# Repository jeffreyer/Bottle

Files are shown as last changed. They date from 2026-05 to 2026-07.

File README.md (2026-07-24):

# Bottle - 可编程 LED 矩阵设备

Bottle 是一个基于 ESP32-S3 的可编程 LED 矩阵设备，支持通过 Lua 脚本创建动态动画效果。它集成了重力感应、音频采集、蓝牙配置等功能，适合创建互动式视觉艺术作品。

## 主要特性

### 硬件能力
- **LED 矩阵**: 17×8 / 32x8 全彩 LED 阵列，支持动态动画
- **重力感应**: LIS3DH 三轴加速度计，支持姿态检测和重力交互
- **音频采集**: 支持 I2S/PDM 麦克风，实时 FFT 频谱分析（17 / 32 频段）
- **音频录制**: 支持录制原始 PCM 音频到 U盘
- **触摸控制**: 电容触摸按键，支持短按、长按、超长按
- **蓝牙功能**: 
  - BLE 配置服务（通过手机 App 配置设备）
  - BLE HID 鼠标模式（将设备用作蓝牙鼠标）
- **USB 功能**: 
  - **USB 复合设备**: 同时支持串口（CDC）和 U盘（MSC）
  - **串口调试**: 始终可用
- **电源管理**: 电池电量监测、自动休眠、低功耗模式

### 软件特性
- **Lua 脚本引擎**: 基于 Lua 5.4.7，支持热加载动画模块
- **模块化架构**: 内置多种动画效果（文字滚动、频谱显示、重力粒子、沙漏、蜡烛等）
- **云端配置**: 支持通过蓝牙从云端下载和配置模块
- **安全机制**: 栈溢出保护、数组边界检查、指令限制
- **持久化存储**: NVS 配置存储、Flash 文件系统

## 硬件设计

本项目包含完整的硬件设计文件（Altium Designer 格式）：

- **PCB 设计**: [Hardware](Hardware/) 目录
  - 硬件组装说明: [README.md](Hardware/README.md)
  - 主板原理图: [main.schdoc](Hardware/main.schdoc)
  - LED 阵列原理图: [led_array.schdoc](Hardware/led_array.schdoc)
  - PCB 布局: [bottle.PcbDoc](Hardware/bottle.PcbDoc)
  - Gerber 文件: [Gerber.rar](Hardware/Gerber.rar)

**核心器件**:
- MCU: ESP32-S3 (N4R2 配置 - 4MB Flash, 2MB PSRAM)
- 加速度计: LIS3DH
- LED: WS2812B 阵列
- 麦克风: I2S/PDM 数字麦克风（板子支持MSM261D3526Z1CM，MSM261S3526Z0CM，可通过串口命令 mic=1/0 切换）

## 快速开始

### 环境准备

1. **安装开发工具**
   - [Visual Studio Code](https://code.visualstudio.com/)
   - [PlatformIO IDE](https://platformio.org/install/ide?install=vscode) 扩展

2. **克隆仓库**
   ```bash
   git clone <repo-url>
   cd Bottle
   ```

### 编译和上传
- 当前有长短版两个版本，编译前需要修改common.h文件，修改第21行，BOTTLE_V4为长版32\*8像素，注释掉为短版17\*8像素，根据需要选择是否注释
```bash
# 编译固件
pio run

# 上传代码到 ESP32-S3
pio run -t upload

# 上传Lua配置文件到 ESP32-S3，或者执行PlatformIO任务里Upload Filesystem Image命令
pio run -t uploadfs

# 打开串口监视器
pio device monitor
```

### 基本操作

**触摸按键控制**:
- **短按**: 切换子页面/模式
- **长按 (大于1秒)**: 正常模式时：在切换动画模块/蓝牙配置模式/关机功能循环，松开即执行显示的功能；蓝牙模式时：在退出蓝牙模式/关机功能循环
- **超长按 (>15秒)**: 强制关机

## Lua 脚本开发

Bottle 支持通过 Lua 脚本创建自定义动画效果。详细的 API 文档和示例请参考：

- **Lua模拟器**: [ESP32 Lua LED Matrix Simulator 使用说明](tools/lua-simulator/README.md)
- **[Lua 脚本开发指南 📖](docs/LUA_SCRIPT_GUIDE.md)**

### 快速示例

```lua
-- @name: 彩虹波浪
-- @version: 1.0.0
-- @author: Your Name
-- @description: Rainbow wave animation
-- @id: rainbow

function setup()
  led.clear()
  led.show()
end

function loop()
  local t = time.millis() / 50
  
  for x = 0, WIDTH - 1 do
    for y = 0, HEIGHT - 1 do
      local hue = (x * 15 + y * 10 + t) % 255
      local r, g, b = led.hsv(hue, 255, 255)
      led.set(x, y, r, g, b)
    end
  end
  
  led.show()
  time.delay(30)
end

function unload()
  led.clear()
  led.show()
end
```

### 可用的硬件 API

- **LED 控制**: 
  - `led.set(x, y, r, g, b)` - 设置像素颜色
  - `led.clear()` - 清空显示
  - `led.show()` - 刷新显示
  - `led.text(x, y, text, r, g, b)` - 绘制文本
  - `led.hsv(h, s, v)` - HSV 转 RGB（返回 r, g, b）
  - `led.palette(palette, index, brightness)` - 调色板插值
- **时间**: 
  - `time.millis()` - 获取运行时间（毫秒）
  - `time.delay(ms)` - 延迟
- **重力感应**: 
  - `gravity.get()` - 返回 gx, gy, gz, valid（**注意：需要对调 x-y 轴**）
- **音频频谱**: 
  - `fft.get(index)` - 获取频段幅度（**需要归一化：除以 10000.0**）
  - `fft.count()` - 返回 512（频段数量）
- **按键**: 
  - `button.poll()` - 返回事件类型（0=无, 1=单击, 2=长按）
  - `button.is_holding()` - 检测是否按住

**坐标系**: 左下角为 (0, 0)，右上角为 (16, 7)

## 内置动画模块

- **文字显示** (`text`) - 支持滚动文字、自定义颜色
- **频谱显示** (`rhythm`) - 音频频谱可视化
- **重力粒子** - 重力感应控制的粒子效果
- **沙漏** (`sandglass`) - 重力感应沙漏模拟
- **蜡烛** (`candle`) - 蜡烛火焰动画
- **水波模拟** (`water_sim`) - 流体动力学模拟
- **RGB 彩虹** (`rgb`) - 彩虹渐变动画
- 以上部分模块需通过小程序**幻彩抽屉**下载

## 蓝牙配置

设备支持通过 BLE 进行配置：

1. 长按触摸键 2-3 秒待 LED 矩阵显示蓝牙图标进入 BLE 配置模式
2. 使用微信小程序**幻彩抽屉**连接设备（设备名: "BottleLED"）
3. 通过 小程序 配置模块参数、下载新模块、调整系统设置
4. 再次长按退出配置模式

## 音频功能

### 实时频谱分析
- 17 / 32 频段 FFT 分析（0-8kHz）
- 支持 I2S 和 PDM 麦克风
- 可用于音乐可视化、声控动画

### 音频录制
- 录制格式: 16-bit PCM, 16kHz 采样率
- 存储位置: `/extflash/rec_*.pcm`
- 通过 USB U盘导出录音文件

## 电源管理

- **电池监测**: 实时监测电池电压
- **自动休眠**: 可配置的空闲超时（默认 60 秒）
- **低功耗模式**: 休眠时关闭 LED、传感器、蓝牙
- **唤醒方式**: 触摸按键唤醒

## 开发和调试

### USB 复合设备

设备使用 **USB 复合设备模式**，同时提供串口和 U盘功能：

**串口（CDC）**:
- 始终可用
- 波特率: 115200
- 用于调试输出和命令行交互

**U盘（MSC）**:
- 可通过串口命令 `usb=1` 启用（可选）
- 启用后设备会显示为 USB 大容量存储设备
- 可访问 `/extflash` 分区
- 用于上传 Lua 脚本、导出录音文件等
- 串口和 U盘可以同时使用

**使用流程**:
```bash
# 1. 连接 USB 线到电脑
# 2. 打开串口终端（115200 波特率）
pio device monitor
# 3. 电脑会识别出 U盘，可以读写文件
# 4. 串口功能始终可用，可以同时调试
```

**重新烧录**:
```bash
# 0. 第一次烧录不需要参考此流程
# 1. 连接 USB 线到电脑
# 2. 打开串口终端（115200 波特率）
# 3. 发送命令 dfu
# 4. 设备会重启进入下载模式
```

**注意事项**:
- U盘模式启用时，设备内部无法访问 `/extflash` 文件系统
- 拔出Type-C数据线，文件系统会自动重新挂载
- 串口和U盘可以同时工作，互不干扰

### 串口调试

设备通过 USB 串口输出调试信息（115200 波特率）：

```bash
# 使用 PlatformIO 监视器
pio device monitor

# 或使用其他串口工具
# Windows: PuTTY, TeraTerm
# Linux/Mac: screen, minicom
```

### 添加新模块

1. 在 [src/](src/) 目录创建模块源文件
2. 实现 `setup()`, `loop()`, `unload()` 函数
3. 在 [module_registry.cpp](src/module_registry.cpp) 注册模块
4. 重新编译上传

或者使用 Lua 脚本（推荐）：

1. 编写 Lua 脚本和配置项（参考 [Lua 开发指南](docs/LUA_SCRIPT_GUIDE.md)）
2. 放入U盘扩展名*.lua(代码文件),*.cfg(配置项文件)
3. 无需重新编译固件

## 依赖库

- **[FastLED](https://github.com/FastLED/FastLED)** (v3.10.3) - LED 控制库
- **[arduinoFFT](https://github.com/kosme/arduinoFFT)** (v2.0.4) - FFT 实现
- **[NimBLE-Arduino](https://github.com/h2zero/NimBLE-Arduino)** (v2.3.9) - 蓝牙协议栈
- **[HijelHID_BLEMouse](https://github.com/HijelHub/HijelHID_BLEMouse)** - BLE HID 鼠标库
- **Lua 5.4.7** - 脚本引擎

## 贡献指南

欢迎贡献代码、报告问题或提出建议！

1. Fork 本仓库
2. 创建特性分支 (`git checkout -b feature/AmazingFeature`)
3. 提交更改 (`git commit -m 'Add some AmazingFeature'`)
4. 推送到分支 (`git push origin feature/AmazingFeature`)
5. 提交 Pull Request

**贡献内容**:
- 新的 Lua 动画模块
- 硬件改进和优化
- Bug 修复
- 文档改进
- 性能优化

## 许可证

- **固件代码**: [GPLv3](https://www.gnu.org/licenses/gpl-3.0.html)
- **硬件设计**: [CC BY-NC-SA 4.0](https://creativecommons.org/licenses/by-nc-sa/4.0/)

**商业使用需获得作者书面许可。**

## 致谢
- **好心却黑猫35** - [我制作了一瓶电子海洋](https://www.bilibili.com/video/BV1f2PezXEso/)
- **FastLED** - 强大的 LED 控制库
- **arduinoFFT** - 高效的 FFT 实现
- **Lua** - 优雅的嵌入式脚本语言
- **ESP32 Arduino Core** - ESP32 开发框架
- **NimBLE** - 轻量级蓝牙协议栈

## 联系方式

- **问题反馈**: 请在 GitHub Issues 提交
- **联系作者**: 不爱吃炸鸡ab6 （全网同名）

---

**版本**: 2.2  
**硬件版本**: Bottle v2.2 PCBA

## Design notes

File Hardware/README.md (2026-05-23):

# 硬件组装注意事项
- 元件焊接图可参考PnPout/bottle.html
- 不要焊接R18, R19，这是硬复位用的，除非设备起不来没串口，可短接R18同时短接R19，再依次断开R19，R18，可将设备切换到下载模式
- 额外需要焊接一个R0603的10uF电容到电池正负极焊盘，对于没焊接电池只用Type-C供电的场景必备，否则会闪屏

# 贴片顺序
- 优先用210°左右的焊锡焊接LED灯阵列，再用低温锡焊接另一侧
- LED阵列焊完测试方法：靠近Type-C一侧有2个测试点：LED正极，DIN，用Type-C座子引脚作为负极，用一块开发板写入颜色交替闪烁的的程序即可测试是否焊接正常

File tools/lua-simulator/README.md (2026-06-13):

# ESP32 Lua LED Matrix Simulator

PC端ESP32 Lua动画模拟器，用于提高Lua脚本开发效率。

## 功能特性

✅ **可视化LED矩阵** - 实时显示32x8或17x8 LED动画效果  
✅ **完整API模拟** - 支持led、fft、gravity、button、time等所有API  
✅ **交互控制** - 键盘鼠标模拟重力感应和按键  
✅ **热重载** - 按R键快速重新加载脚本  
✅ **配置支持** - 自动加载.cfg配置文件  
✅ **暂停/恢复** - 空格键暂停动画观察细节  

## 安装依赖

```bash
pip install pygame
```

**可选：完整Lua支持**
```bash
pip install lupa
```

## 使用方法

### 基本用法

```bash
# 运行长版音乐律动
python simulator.py ../../data/rhythm-long.lua --config ../../data/rhythm-long.cfg

# 运行彩色波浪（32x8）
python simulator.py ../../data/colorwave.lua --width 32 --height 8

# 运行短版时钟（17x8）
python simulator.py ../../data/clock.lua --width 17 --height 8
```

### 命令行参数

```
python simulator.py <lua文件> [选项]

必需参数:
  lua文件          要运行的Lua脚本文件路径

可选参数:
  --config FILE    配置文件路径(.cfg格式)
  --width N        LED矩阵宽度（默认32）
  --height N       LED矩阵高度（默认8）
```

## 键盘控制

| 按键 | 功能 |
|---|---|
| **空格** | 暂停/恢复动画 |
| **R** | 重新加载Lua脚本（重新调用setup） |
| **↑** | 模拟设备向前倾斜（gx=0.5） |
| **↓** | 模拟设备向后倾斜（gx=-0.5） |
| **←** | 模拟设备向左倾斜（gy=-0.5） |
| **→** | 模拟设备向右倾斜（gy=0.5） |
| **鼠标左键** | 模拟按键单击/长按 |
| **ESC** | 退出模拟器 |

## 支持的API

### LED控制
- ✅ `led.set(x, y, r, g, b)` - 设置单个像素
- ✅ `led.clear()` - 清空显示
- ✅ `led.show()` - 刷新显示
- ✅ `led.hsv(h, s, v)` - HSV转RGB
- ✅ `led.text(x, y, text, r, g, b)` - 绘制文本
- ✅ `led.palette(palette, index, brightness)` - 调色板

### 音频FFT
- ✅ `fft.get(index)` - 获取频段值（模拟数据）
- ✅ `fft.count()` - 返回512

### 重力感应
- ✅ `gravity.get()` - 返回gx, gy, gz, valid
- 🎮 方向键控制倾斜

### 按键
- ✅ `button.poll()` - 获取按键事件
- ✅ `button.is_holding()` - 是否按住
- 🎮 鼠标左键模拟

### 时间
- ✅ `time.millis()` - 毫秒时间戳
- ✅ `time.delay(ms)` - 延迟（在模拟器中忽略）
- ✅ `time.now()` - 当前时间

### 全局变量
- ✅ `WIDTH` - 矩阵宽度
- ✅ `HEIGHT` - 矩阵高度
- ✅ `CONFIG` - 配置表

## 示例

### 示例1：测试彩色波浪

```bash
cd tools/lua-simulator
python simulator.py test_colorwave.py
```

### 示例2：测试自己的脚本

创建 `my_animation.lua`:
```lua
-- @name: 我的动画
-- @id: my-animation

function setup()
  print("动画初始化")
end

function loop()
  led.clear()
  
  -- 绘制一个移动的点
  local x = math.floor((time.millis() / 50) % WIDTH)
  led.set(x, HEIGHT / 2, 255, 0, 0)
  
  led.show()
  time.delay(30)
end

function unload()
  print("动画卸载")
end
```

运行：
```bash
python simulator.py my_animation.lua
```

## 项目结构

```
tools/lua-simulator/
├── simulator.py          # 主模拟器程序
├── README.md            # 本文件
├── test_colorwave.py    # 测试脚本：彩色波浪
└── requirements.txt     # Python依赖
```

## 配置文件格式

配置文件采用JSON格式（.cfg扩展名）：

```json
[
  {
    "key": "move_interval",
    "type": "slider",
    "label": "滚动速度",
    "default": 30,
    "min": 1,
    "max": 60
  },
  {
    "key": "main_color",
    "type": "color",
    "label": "主要颜色",
    "default": "#FF8800"
  }
]
```

模拟器会自动提取 `key` 和 `default` 字段到 `CONFIG` 表。

## 限制和注意事项

### 当前限制

1. **不是真正的Lua解释器** - 当前版本使用Python模拟，不能运行实际的Lua代码
2. **FFT数据为模拟** - 音频数据使用数学函数模拟，不是真实麦克风输入
3. **文字渲染简化** - 仅支持数字和部分大写字母
4. **性能差异** - PC上的表现可能与实际ESP32设备不同

### 升级到完整Lua支持

要支持真正的Lua代码执行，需要：

1. 安装lupa: `pip install lupa`
2. 修改 `simulator.py` 中的Lua执行部分
3. 使用lupa的LuaRuntime替代Python模拟

示例代码片段（需要集成到simulator.py）：
```python
from lupa import LuaRuntime

lua = LuaRuntime(unpack_returned_tuples=True)

# 注入API到Lua环境
lua_globals = lua.globals()
lua_globals.WIDTH = width
lua_globals.HEIGHT = height
lua_globals.led = led_api
lua_globals.fft = fft_api
# ... 其他API

# 执行Lua代码
lua.execute(lua_code)

# 调用Lua函数
if 'setup' in lua_globals:
    lua_globals.setup()
```

## 开发工作流

### 推荐工作流程

1. **在模拟器中快速迭代** - 修改Lua代码，按R键热重载
2. **验证动画效果** - 使用键盘模拟重力，鼠标模拟按键
3. **调整配置参数** - 修改.cfg文件，重启模拟器查看效果
4. **上传到设备测试** - 确认无误后上传到ESP32实际测试

### 调试技巧

1. **使用print调试** - print输出会显示在终端
2. **暂停观察** - 空格键暂停，仔细观察每一帧
3. **修改像素大小** - 编辑simulator.py中的PIXEL_SIZE参数
4. **降低帧率** - 编辑FPS参数，方便观察慢动画

## 扩展功能

### 添加真实音频输入

可以集成 `pyaudio` 实现真实FFT：

```python
import pyaudio
import numpy as np

# 音频回调
def audio_callback(in_data, frame_count, time_info, status):
    audio_data = np.frombuffer(in_data, dtype=np.int16)
    fft_data = np.fft.fft(audio_data)
    fft_api.data = np.abs(fft_data[:512])
    return (in_data, pyaudio.paContinue)
```

### 添加视频录制

使用 `pygame-recorder` 或 `opencv` 录制动画为视频文件。

### 添加性能分析

统计每帧执行时间，找出性能瓶颈：

```python
import cProfile
cProfile.run('simulator.call_loop()')
```

## 故障排除

### Q: 窗口显示不正常
A: 检查分辨率设置，尝试调整PIXEL_SIZE和PIXEL_GAP参数

### Q: 帧率很低
A: 降低FPS参数，或优化Lua代码中的循环

### Q: Lua脚本报错
A: 当前版本不支持真实Lua执行，需要安装lupa库

### Q: FFT数据不变化
A: 当前为模拟数据，可以集成pyaudio获取真实音频

## 贡献

欢迎提交Issue和Pull Request改进模拟器！

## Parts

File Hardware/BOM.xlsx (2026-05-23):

ID | Name | Value | Footprint | Quantity | Memo
1 | X1 | 40MHz | CRYSTAL-SMD_4P-L2.5-W2.0-BL | 1
2 | U142 | W25Q256JVEIQ | WSON-8_L8.0-W6.10-P1.27-BL-EP-MINI | 1
3 | USB1 | KH-TYPEC-16P | USB-TYPEC-16P-SMD | 1
4 | U141 | RT9013-33GB | SOT-23-5_L3.0-W1.7-P0.95-LS2.8-BL | 1
5 | U138 | LTC4054 | SOT-23-5_L3.0-W1.7-P0.95-LS2.8-BL | 1
6 | U140 | ESP32-S3R8 | QFN-56_L7.0-W7.0-P0.40-TL-EP4.0 | 1
7 | U137 | MSM261D3526Z1CM | MIC-SMD_6P-L3.5-W2.7-P0.90-TR | 1
8 | U139 | LIS3DHTR | LGA-16_L3.0-W3.0-P0.50-TL | 1
9 | U1, U2, U3, U4, U5, U6, U7, U8, U9, U10, U11, U12, U13, U14, U15, U16, U17, U18, U19, U20, U21, U22, U23, U24, U25, U26, U27, U28, U29, U30, U31, U32, U33, U34, U35, U36, U37, U38, U39, U40, U41, U42, U43, U44, U45, U46, U47, U48, U49, U50, U51, U52, U53, U54, U55, U56, U57, U58, U59, U60, U61, U62, U63, U64, U65, U66, U67, U68, U69, U70, U71, U72, U73, U74, U75, U76, U77, U78, U79, U80, U81, U82, U83, U84, U85, U86, U87, U88, U89, U90, U91, U92, U93, U94, U95, U96, U97, U98, U99, U100, U101, U102, U103, U104, U105, U106, U107, U108, U109, U110, U111, U112, U113, U114, U115, U116, U117, U118, U119, U120, U121, U122, U123, U124, U125, U126, U127, U128, U129, U130, U131, U132, U133, U134, U135, U136 | XL-1010RGBC-2812B | LED-SMD_4P-L1.0-W1.0-TL_XL-1010RGBC-WS2812B | 136
10 | R3, R4, R12, R13 | 5.1k | r0402 | 4
11 | R11 | 22r | r0402 | 1
12 | R21 | 1kΩ | r0402 | 1
13 | R1, R2, R5, R16 | 10k | r0402 | 4
14 | R20 | 100kΩ | r0402 | 1
15 | R22 | 3K | R0402 | 1
16 | R10 | 240r | R0402 | 1
17 | R6, R17 | 0r | R0402 | 2
~~18~~ | ~~R18, R19~~ | ~~0r~~ | ~~R0402~~ | ~~2~~ | 不需要焊接，仅占位，用于手动复位
19 | Q1 | AO3401A | SOT-23-3_L2.9-W1.6-P1.90-LS2.8-BR_1 | 1
20 | Q3 | AO3401A | SOT-23-3_L2.9-W1.3-P1.90-LS2.4-BR | 1
21 | LED1 | LED-0402 | c0402 | 1 | 红色充电提示
22 | L3 | 3nH | c0402 | 1
23 | L2 | 2nH | c0402 | 1
24 | L4 | 24nH | c0402 | 1
25 | D2 | SS34_C9900020624 | SMA_L4.3-W2.6-LS5.1-R-RD | 1
26 | C5 | 47uF | c0603 | 1
27 | C19, C20 | 10uF | c0402 | 2
28 | C22 | 100nF | c0402 | 1
29 | C7, C12, C23 | 1uF | C0402 | 3
30 | C1, C2 | 15pF | C0402 | 2
31 | C3, C8 | 10uF | C0402 | 2
32 | C4, C6, C9, C10, C11, C17, C18, C21 | 100nF | C0402 | 8
33 | AE1 | ANT5520 | ANT_5520 | 1
34 | C_bat | 10uF | C0603 | 1 | 建议焊接，焊在电池焊盘上，仅typec供电时需要
35 | 透明圆管 | 关键词：粉刺针化妆刷子PC/PVC包装管透明圆管收纳包装钻头轴承塑料包装管 | 长度60mm，外径19mm*内径18mm | 1
36 | 锂电池 | 关键词：3.7V聚合物锂电池601235/501235/401235/401230适用固定式电子设备 | 601245-400毫安 | 1
37 | 瓶盖，瓶内中框 | 3D打印，参考3D结构件目录 |  | 1
38 | 触摸感应圆片 | 关键词：圆形超薄铁片厚度0.3/0.5mm 电镀锌板材引磁导电防锈粉刷挂墙面网 | 5*0.3 | 1

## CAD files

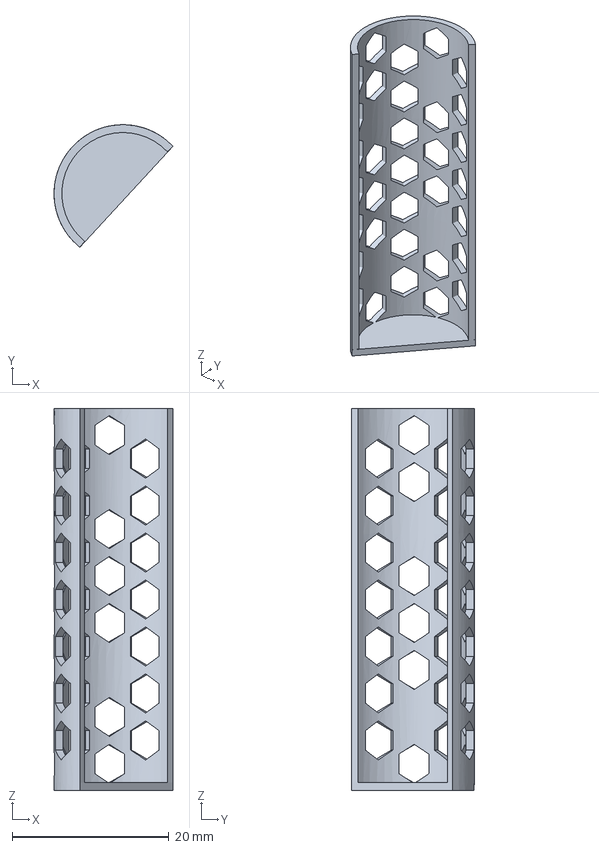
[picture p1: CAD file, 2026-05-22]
Hardware/3D结构件/瓶内中框v2.3MF
15.2 x 15.7 x 48.8 mm

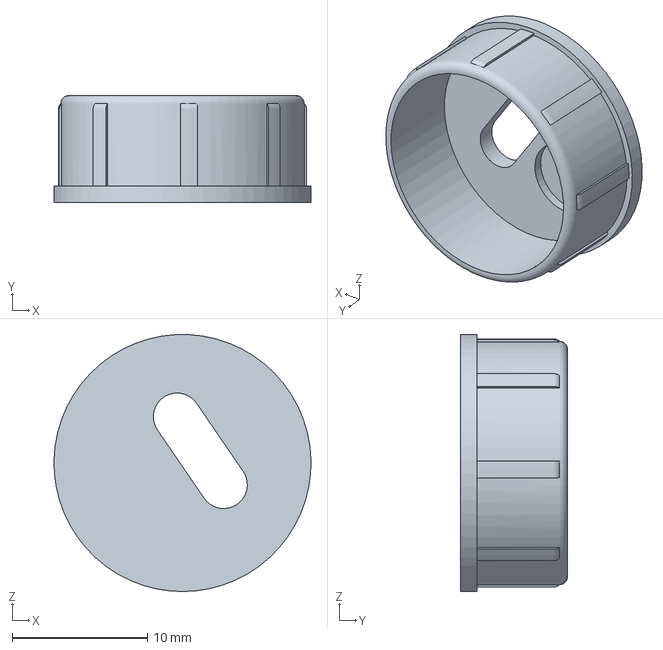
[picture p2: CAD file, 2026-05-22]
Hardware/3D结构件/瓶盖v2.3MF
19.0 x 7.90 x 19.0 mm

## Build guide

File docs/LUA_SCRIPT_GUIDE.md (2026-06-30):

# Lua 动画开发指南

本文档为 AI 助手和开发者提供快速开发 Lua 动画模块的完整指南。

## 目录
- [硬件环境](#硬件环境)
- [文件结构](#文件结构)
- [核心 API](#核心-api)
- [动画开发模式](#动画开发模式)
- [常见问题](#常见问题)
- [最佳实践](#最佳实践)

---

## 硬件环境
有两个硬件版本，核心区别：长版LED矩阵32×8，短版LED矩阵17×8，在开发时需要兼容两个版本，尽量同一份代码适配两个版本，如无法适配可为两个版本单独开发；长版在连接小程序时应答元数据model=Bottle-V4，短版应答元数据model=Bottle-V1。
### LED 矩阵
- **尺寸**: 长版：32 宽 × 8 高 (`MATRIX_WIDTH = 32`, `MATRIX_HEIGHT = 8`)；短版：17 宽 × 8 高 (`MATRIX_WIDTH = 17`, `MATRIX_HEIGHT = 8`)
- **全局变量**: `WIDTH` 和 `HEIGHT` 由设备端注册，**不要硬编码**
- **坐标系**: 长版：左下角为 (0, 0)，右上角为 (31, 7)；短版：左下角为 (0, 0)，右上角为 (16, 7)

### 传感器
- **加速度计**: 提供重力感应，**注意 x-y 轴需要对调**
- **麦克风**: 提供 FFT 音频数据，512 个频段
- **按键**: 支持单击和长按事件

---

## 文件结构

### 必需的文件头元数据
```lua
-- @name: 模块名称
-- @version: 1.0.0
-- @author: Bottle Team
-- @description: 中文描述（必须使用中文）
-- @id: module-id-kebab-case
```

**重要**: 
- `@id` 和文件名**不要使用下划线 `_`**，使用连字符 `-` 代替
- 下划线是内部分隔符，会导致解析错误
- ✅ 正确：`wooden-fish.lua`, `@id: wooden-fish`
- ❌ 错误：`wooden_fish.lua`, `@id: wooden_fish`

**字段长度限制**：
- `@description` 字段**必须控制在 128 字节以内**
- 中文字符通常占 3 字节（UTF-8 编码）
- **建议不超过 42 个中文字符**（约 126 字节）
- 超过限制会导致 BLE 传输时被截断，出现乱码

### 标准三函数结构
#### `setup()`
- 模块加载时调用一次
- 用于初始化状态、加载配置、设置硬件
- 可选函数

#### `loop()`
- 主循环，持续调用
- 实现模块的主要逻辑
- 必需函数

#### `unload()`
- 模块卸载时调用
- 用于清理资源、保存状态
- 可选函数

### 读取配置
- 配置通过全局 `CONFIG` 表访问

```lua
use("button")  -- 声明使用的硬件资源
use("gravity")
use("audio")

-- 配置参数（正确处理布尔值）
local my_param = CONFIG.my_param or 10
local my_bool = true
if CONFIG.my_bool ~= nil then
  my_bool = CONFIG.my_bool
end

-- 状态变量
local animation_progress = 0.0
local last_frame_time = 0

function setup()
  print("Module loaded")
  last_frame_time = time.millis()
end

function loop()
  local current_time = time.millis()
  local dt = (current_time - last_frame_time) / 1000.0
  last_frame_time = current_time
  
  -- 更新逻辑
  -- 绘制逻辑
  
  led.show()
  time.delay(16)  -- ~60 FPS
end

function unload()
  print("Module unloaded")
  led.clear()
  led.show()
end
```

---

## 核心 API

### LED 控制

#### `led.set(x, y, r, g, b)`
设置单个像素的 RGB 颜色。
```lua
led.set(0, 0, 255, 0, 0)  -- 左上角设为红色
```

#### `led.hsv(h, s, v) -> r, g, b`
**颜色转换函数**，返回 RGB 值（不是直接设置像素）。
```lua
-- 错误用法
led.hsv(x, y, 120, 255, 200)  -- ❌ 参数错误

-- 正确用法
local r, g, b = led.hsv(120, 255, 200)  -- ✅ 转换颜色
led.set(x, y, r, g, b)  -- ✅ 设置像素
```

**为什么用 HSV？**
- **H (色相)**: 通过配置改变整体颜色风格
- **S (饱和度)**: 控制颜色鲜艳程度
- **V (亮度)**: 方便实现渐变、脉动、淡入淡出

#### `led.text(x, y, text, r, g, b)`
绘制文本（3×5 字体）。
```lua
led.text(10, 2, "99", 255, 255, 0)  -- 黄色文字
```

**字体特性**：
- 3x5 像素字体
- 支持大写字母 A-Z
- 支持小写字母 a-z（较小）
- 支持数字 0-9
- 支持常用符号（空格、标点、运算符等）
- 字符间距：4 像素（3 像素字符 + 1 像素间距）

#### `led.palette(palette_table, index, brightness) -> r, g, b`
从调色板插值获取颜色。

**参数**：
- `palette_table`: 调色板表，每个条目格式为 `{position, r, g, b}`
- `index`: 颜色索引 (0-255)
- `brightness`: 亮度 (0-255，可选，默认 255)

**返回**：`r, g, b` (0-255)

**工作原理**：
- 在调色板中找到 index 两侧的颜色条目
- 使用线性插值计算中间颜色
- 应用亮度调整

```lua
-- 定义彩虹调色板
local rainbow_palette = {
  {0,   255, 0,   0},    -- 红色
  {85,  255, 255, 0},    -- 黄色
  {170, 0,   255, 0},    -- 绿色
  {255, 0,   0,   255}   -- 蓝色
}

-- 获取索引 128 处的颜色（绿色和黄色之间）
local r, g, b = led.palette(rainbow_palette, 128, 255)
led.set(0, 0, r, g, b)

-- 使用调色板创建渐变效果
for x = 0, 16 do
  local index = math.floor((x / 16) * 255)
  local r, g, b = led.palette(rainbow_palette, index, 200)
  led.set(x, 4, r, g, b)
end
```

**使用场景**：
- 创建平滑的颜色渐变
- 实现彩虹效果
- 音频可视化的颜色映射
- 热力图显示

#### `led.clear()` / `led.show()`
清空缓冲区 / 刷新显示。

### 音频 FFT

#### `fft.get(index) -> magnitude`
获取指定频段的幅度值（**原始值很大，需要归一化**）。
```lua
local value = fft.get(10)
value = value / 10000.0  -- ✅ 归一化到 0-1 范围
```

#### `fft.count() -> 512`
返回 FFT 频段数量（固定 512）。

**频段映射**（采样率 16kHz）：
- 0-10: 低音 (0-100Hz)
- 10-200: 中音 (100-2000Hz)
- 200-400: 高音 (2000-4000Hz)

**重要**: 所有使用 FFT 的代码必须归一化，否则会导致显示异常。

### 重力感应

#### `gravity.get() -> gx, gy, gz, valid`
获取加速度计数据。

**关键**: **必须对调 x-y 轴**
```lua
local gx, gy, gz, valid = gravity.get()
if valid then
  gx, gy = gy, gx  -- ✅ 对调 x-y 轴
  -- 使用 gx, gy, gz
end
```

### 按键

#### `button.poll() -> event_type`
返回按键事件：
- `0`: 无事件
- `1`: 单击
- `2`: 长按

```lua
local event = button.poll()
if event > 0 then  -- 单击或长按
  trigger_action()
end
```

#### `button.is_holding() -> boolean`
检测按键是否被按住（用于持续检测，不是事件）。

### 时间

#### `time.millis() -> milliseconds`
返回启动后的毫秒数。

#### `time.delay(ms)`
阻塞延迟（通常用 16ms 实现 60 FPS）。

---

## 动画开发模式

### 模式 1: 基于时间的动画

使用独立的帧时间计算，避免时间重置问题。

```lua
local animation_progress = 0.0
local last_frame_time = 0

function setup()
  last_frame_time = time.millis()
end

function loop()
  local current_time = time.millis()
  local dt = (current_time - last_frame_time) / 1000.0
  last_frame_time = current_time
  
  -- 更新动画
  if animation_progress > 0.0 then
    animation_progress = animation_progress - dt * 2.0  -- 衰减速度
    if animation_progress < 0.0 then
      animation_progress = 0.0
    end
  end
  
  -- 绘制
  draw_with_animation(animation_progress)
end
```

**关键点**:
- 使用 `last_frame_time` 而不是事件时间
- `dt` 是帧间隔（秒），用于平滑动画
- 每帧更新 `last_frame_time`

### 模式 2: 缩放动画

```lua
local function draw_scaled_object(scale)
  -- scale: 1.0 = 正常, 0.8 = 缩小到 80%
  
  for y = 0, HEIGHT - 1 do
    for x = 0, WIDTH - 1 do
      -- 计算相对于中心的位置
      local cx = WIDTH / 2
      local cy = HEIGHT / 2
      local dx = x - cx
      local dy = y - cy
      
      -- 应用缩放
      local sx = cx + dx * scale
      local sy = cy + dy * scale
      
      -- 判断原始位置是否应该绘制
      local ix = math.floor(sx + 0.5)
      local iy = math.floor(sy + 0.5)
      
      if should_draw_at(ix, iy) then
        led.set(x, y, r, g, b)
      end
    end
  end
end
```

### 模式 3: 简化缩放（跳过像素）

```lua
local function draw_with_shrink(shrink)
  local function set_pixel(x, y, r, g, b)
    if shrink then
      -- 跳过边缘像素实现缩小效果
      if x == 0 or x == WIDTH-1 or y == 0 or y == HEIGHT-1 then
        return
      end
    end
    led.set(x, y, r, g, b)
  end
  
  -- 使用 set_pixel 绘制所有像素
  set_pixel(2, 3, 255, 0, 0)
end
```

### 模式 4: 颜色渐变

```lua
local function draw_gradient(progress)
  -- progress: 0.0 -> 1.0
  
  for x = 0, WIDTH - 1 do
    local intensity = (x / WIDTH) * progress
    local brightness = math.floor(intensity * 255)
    local r, g, b = led.hsv(120, 255, brightness)
    led.set(x, 4, r, g, b)
  end
end
```

---

## 常见问题

### 问题 1: 硬编码 WIDTH/HEIGHT

❌ **错误**:
```lua
local WIDTH = 16
local HEIGHT = 16
```

✅ **正确**:
```lua
-- WIDTH 和 HEIGHT 是全局变量，直接使用
local CENTER_X = WIDTH / 2
local CENTER_Y = HEIGHT / 2
```

### 问题 2: 错误使用 led.hsv

❌ **错误**:
```lua
led.hsv(x, y, 120, 255, 200)  -- 参数错误
```

✅ **正确**:
```lua
local r, g, b = led.hsv(120, 255, 200)
led.set(x, y, r, g, b)
```

### 问题 3: 布尔值配置错误

❌ **错误**:
```lua
local my_bool = CONFIG.my_bool or true
-- 问题：当 CONFIG.my_bool = false 时，结果仍为 true
```

✅ **正确**:
```lua
local my_bool = true
if CONFIG.my_bool ~= nil then
  my_bool = CONFIG.my_bool
end
```

### 问题 4: FFT 未归一化

❌ **错误**:
```lua
local value = fft.get(10)
-- value 可能是几千，导致显示异常
```

✅ **正确**:
```lua
local value = fft.get(10)
value = value / 10000.0  -- 归一化
```

### 问题 5: 重力轴向错误

❌ **错误**:
```lua
local gx, gy, gz, valid = gravity.get()
-- 直接使用 gx, gy
```

✅ **正确**:
```lua
local gx, gy, gz, valid = gravity.get()
if valid then
  gx, gy = gy, gx  -- 对调 x-y 轴
  -- 使用对调后的值
end
```

---

## 最佳实践

### 1. 配置文件编写指南

#### 配置文件格式

创建 `[module-id].cfg`（JSON 数组格式）：

```json
[
  {
    "key": "main_color",
    "type": "color",
    "label": "主要颜色",
    "default": "#FF8800",
    "desc": "动画的主要颜色"
  },
  {
    "key": "speed",
    "type": "slider",
    "label": "动画速度",
    "min": 0.5,
    "max": 5.0,
    "step": 0.1,
    "default": 2.0,
    "desc": "动画播放速度"
  },
  {
    "key": "enable_gravity",
    "type": "switch",
    "label": "启用重力感应",
    "default": true,
    "desc": "是否响应设备倾斜"
  }
]
```

#### 配置类型详解

##### 1. color - 颜色选择器

```json
{
  "key": "main_color",
  "type": "color",
  "label": "主要颜色",
  "default": "#FF8800",
  "desc": "动画的主要颜色"
}
```

- **值类型**: 字符串，格式 `"#RRGGBB"`
- **用途**: 提供颜色选择器界面
- **Lua 读取**:
  ```lua
  local color_str = CONFIG.main_color or "#FF8800"
  local function parse_color(hex)
    hex = hex:gsub("#", "")
    local r = tonumber(hex:sub(1, 2), 16)
    local g = tonumber(hex:sub(3, 4), 16)
    local b = tonumber(hex:sub(5, 6), 16)
    return r, g, b
  end
  local r, g, b = parse_color(color_str)
  ```

##### 2. slider - 滑块选择

```json
{
  "key": "speed",
  "type": "slider",
  "label": "速度",
  "min": 0.5,
  "max": 5.0,
  "step": 0.1,
  "default": 2.0,
  "desc": "动画播放速度"
}
```

- **值类型**: 数字
- **必需字段**: `min`, `max`, `step`
- **可选字段**: `unit` (单位，如 "ms", "%")
- **Lua 读取**:
  ```lua
  local speed = CONFIG.speed or 2.0
  ```

##### 3. switch - 开关

```json
{
  "key": "enable_feature",
  "type": "switch",
  "label": "启用功能",
  "default": true,
  "desc": "是否启用该功能"
}
```

- **值类型**: 布尔值 (true/false)
- **Lua 读取** (正确处理):
  ```lua
  local enable_feature = true
  if CONFIG.enable_feature ~= nil then
    enable_feature = CONFIG.enable_feature
  end
  ```
- **注意**: 不要使用 `or` 运算符，会导致 false 被误判为 true

##### 4. select - 下拉选择

```json
{
  "key": "mode",
  "type": "select",
  "label": "显示模式",
  "default": "auto",
  "options": [
    {"value": "static", "label": "静态"},
    {"value": "auto", "label": "自动"},
    {"value": "scroll", "label": "滚动"}
  ],
  "desc": "选择显示模式"
}
```

- **值类型**: 字符串或数字
- **必需字段**: `options` 数组
- **options 格式**: 每个选项包含 `value` 和 `label`
- **Lua 读取**:
  ```lua
  local mode = CONFIG.mode or "auto"
  
  if mode == "static" then
    -- 静态模式逻辑
  elseif mode == "auto" then
    -- 自动模式逻辑
  elseif mode == "scroll" then
    -- 滚动模式逻辑
  end
  ```

**数字值的 select 示例**:
```json
{
  "key": "pattern",
  "type": "select",
  "label": "图案",
  "default": 0,
  "options": [
    {"value": 0, "label": "圆形"},
    {"value": 1, "label": "方形"},
    {"value": 2, "label": "三角形"}
  ],
  "desc": "选择图案类型"
}
```

```lua
local pattern = CONFIG.pattern or 0

if pattern == 0 then
  draw_circle()
elseif pattern == 1 then
  draw_square()
elseif pattern == 2 then
  draw_triangle()
end
```

##### 5. text - 文本输入

```json
{
  "key": "display_text",
  "type": "text",
  "label": "显示文字",
  "default": "Hello",
  "desc": "要显示的文本内容"
}
```

- **值类型**: 字符串
- **Lua 读取**:
  ```lua
  local text = CONFIG.display_text or "Hello"
  ```

##### 6. number - 数字输入

```json
{
  "key": "count",
  "type": "number",
  "label": "数量",
  "default": 10,
  "desc": "粒子数量"
}
```

- **值类型**: 数字
- **Lua 读取**:
  ```lua
  local count = CONFIG.count or 10
  ```

#### 配置最佳实践

**1. 使用 desc 而不是 description**
```json
// ✅ 正确
{"desc": "这是描述"}

// ❌ 错误
{"description": "这是描述"}
```

**2. 颜色配置使用 color 类型**
```json
// ✅ 正确 - 提供颜色选择器
{"type": "color", "default": "#FF8800"}

// ❌ 错误 - 用户体验差
{"type": "slider", "min": 0, "max": 255, "label": "色相"}
```

**3. 布尔值正确处理**
```lua
// ❌ 错误 - false 会被当作 true
local my_bool = CONFIG.my_bool or true

// ✅ 正确
local my_bool = true
if CONFIG.my_bool ~= nil then
  my_bool = CONFIG.my_bool
end
```

**4. Key长度不超过15个字符**
受限于NVS存储key长度限制，所有配置项key长度限制最大为 15 个字符

**5. 提供合理的默认值**
- 确保模块在没有配置时也能正常运行
- 默认值应该是最常用的选项

**6. 描述要清晰**
- 简洁说明配置项的作用
- 必要时说明取值范围或单位

#### 完整配置示例

```json
[
  {
    "key": "main_color",
    "type": "color",
    "label": "主要颜色",
    "default": "#FF8800",
    "desc": "动画的主要颜色"
  },
  {
    "key": "speed",
    "type": "slider",
    "label": "速度",
    "min": 0.5,
    "max": 5.0,
    "step": 0.1,
    "default": 2.0,
    "unit": "倍",
    "desc": "动画播放速度"
  },
  {
    "key": "mode",
    "type": "select",
    "label": "模式",
    "default": "auto",
    "options": [
      {"value": "static", "label": "静态"},
      {"value": "auto", "label": "自动"},
      {"value": "scroll", "label": "滚动"}
    ],
    "desc": "显示模式"
  },
  {
    "key": "enable_gravity",
    "type": "switch",
    "label": "重力感应",
    "default": true,
    "desc": "是否启用重力感应"
  },
  {
    "key": "display_text",
    "type": "text",
    "label": "显示文字",
    "default": "Hello",
    "desc": "要显示的文本"
  },
  {
    "key": "particle_count",
    "type": "number",
    "label": "粒子数量",
    "default": 20,
    "desc": "粒子效果的数量"
  }
]
```

对应的 Lua 读取代码：

```lua
-- 颜色配置
local color_str = CONFIG.main_color or "#FF8800"
local function parse_color(hex)
  hex = hex:gsub("#", "")
  local r = tonumber(hex:sub(1, 2), 16) or 255
  local g = tonumber(hex:sub(3, 4), 16) or 136
  local b = tonumber(hex:sub(5, 6), 16) or 40
  return r, g, b
end
local r, g, b = parse_color(color_str)

-- 数字配置
local speed = CONFIG.speed or 2.0
local particle_count = CONFIG.particle_count or 20

-- 字符串配置
local mode = CONFIG.mode or "auto"
local display_text = CONFIG.display_text or "Hello"

-- 布尔值配置
local enable_gravity = true
if CONFIG.enable_gravity ~= nil then
  enable_gravity = CONFIG.enable_gravity
end
```

### 2. 性能优化

- **避免重复计算**: 在循环外计算颜色
  ```lua
  -- ❌ 每次循环都转换
  for i = 0, 10 do
    local r, g, b = led.hsv(120, 255, 200)
    led.set(i, 0, r, g, b)
  end
  
  -- ✅ 只转换一次
  local r, g, b = led.hsv(120, 255, 200)
  for i = 0, 10 do
    led.set(i, 0, r, g, b)
  end
  ```

- **限制帧率**: 使用 `time.delay(16)` 实现 60 FPS

### 3. 布局设计

对于 17×8 的矩阵，常见布局：
- **左侧 8×8**: 主要内容区域（正方形）
- **右侧 9×8**: 状态信息、文字显示

```lua
-- 左侧：主要动画（0-7）
for x = 0, 7 do
  draw_main_content(x, y)
end

-- 右侧：状态显示（9-16）
led.text(10, 2, "99", 255, 255, 0)
```

### 4. 调试技巧

使用 `print()` 输出调试信息：
```lua
print("Animation progress: " .. animation_progress)
```

输出会显示在设备端串口日志中。

### 5. 资源声明

在文件开头声明使用的硬件资源：
```lua
use("button")   -- 按键
use("gravity")  -- 重力感应
use("audio")    -- 音频/FFT
```

---

## 完整示例：简单脉动动画

```lua
-- @name: 脉动圆点
-- @version: 1.0.0
-- @author: Bottle Team
-- @description: 中心圆点脉动动画
-- @id: pulse-dot

use("button")

-- 配置
local pulse_speed = CONFIG.pulse_speed or 2.0
local color_hue = CONFIG.color_hue or 120

-- 状态
local pulse_phase = 0.0
local last_frame_time = 0

function setup()
  print("Pulse Dot loaded")
  last_frame_time = time.millis()
end

function loop()
  local current_time = time.millis()
  local dt = (current_time - last_frame_time) / 1000.0
  last_frame_time = current_time
  
  -- 更新脉动相位
  pulse_phase = pulse_phase + dt * pulse_speed
  if pulse_phase > 1.0 then
    pulse_phase = pulse_phase - 1.0
  end
  
  -- 计算亮度（正弦波）
  local brightness = (math.sin(pulse_phase * math.pi * 2) + 1) / 2
  brightness = math.floor(brightness * 255)
  
  -- 绘制
  led.clear()
  
  local cx = math.floor(WIDTH / 2)
  local cy = math.floor(HEIGHT / 2)
  local r, g, b = led.hsv(color_hue, 255, brightness)
  
  -- 中心点
  led.set(cx, cy, r, g, b)
  
  -- 周围点（亮度减半）
  local r2, g2, b2 = led.hsv(color_hue, 255, math.floor(brightness * 0.5))
  led.set(cx - 1, cy, r2, g2, b2)
  led.set(cx + 1, cy, r2, g2, b2)
  led.set(cx, cy - 1, r2, g2, b2)
  led.set(cx, cy + 1, r2, g2, b2)
  
  led.show()
  time.delay(16)
end

function unload()
  print("Pulse Dot unloaded")
  led.clear()
  led.show()
end
```

---

## 快速检查清单

开发新模块时，确保：

- [ ] 文件头包含完整元数据（中文 @description）
- [ ] **文件名和 @id 使用连字符 `-`，不使用下划线 `_`**
- [ ] **颜色配置使用 `type: "color"`**
- [ ] **配置项描述使用 `"desc"`，不是 `"description"`**
- [ ] 使用 `setup() / loop() / unload()` 结构
- [ ] 不硬编码 WIDTH/HEIGHT
- [ ] 正确使用 `led.hsv()` 返回值
- [ ] 布尔值配置使用 `if CONFIG.xxx ~= nil then`
- [ ] FFT 数据归一化（除以 10000.0）
- [ ] 重力数据 x-y 轴对调
- [ ] 使用独立的 `last_frame_time` 计算 dt
- [ ] 按键使用 `button.poll()` 返回值
- [ ] 帧率控制 `time.delay(16)`

---

## 更多示例模块

### 示例：文字滚动显示

```lua
-- @name: 文字显示
-- @version: 1.0.0
-- @author: Bottle Team
-- @description: 自定义文字滚动显示
-- @id: text-show

-- 配置
local text = CONFIG.text or "Hello"
local text_color = CONFIG.text_color or "#00FF00"
local scroll_speed = CONFIG.scroll_speed or 100
local scroll_mode = CONFIG.scroll_mode or "auto"
local y_position = CONFIG.y_position or 1

-- 解析颜色
local function parse_color(hex)
  if type(hex) ~= "string" then return 0, 255, 0 end
  hex = hex:gsub("#", "")
  if #hex ~= 6 then return 0, 255, 0 end
  local r = tonumber(hex:sub(1, 2), 16) or 0
  local g = tonumber(hex:sub(3, 4), 16) or 255
  local b = tonumber(hex:sub(5, 6), 16) or 0
  return r, g, b
end

-- 状态变量
local scroll_offset = 0
local last_scroll_time = 0
local text_width = #text * 4
local r, g, b = parse_color(text_color)

function setup()
  print("Text Display loaded")
  led.clear()
  led.show()
end

function loop()
  local current_time = time.millis()
  led.clear()

  if scroll_mode == "static" then
    -- 静态显示
    local x_pos = 0
    if text_width <= 17 then
      x_pos = math.floor((17 - text_width) / 2)
    end
    led.text(x_pos, y_position, text, r, g, b)
  else
    -- 滚动显示
    if current_time - last_scroll_time >= scroll_speed then
      scroll_offset = scroll_offset + 1
      if scroll_offset > text_width + 17 then
        scroll_offset = 0
      end
      last_scroll_time = current_time
    end
    local x_pos = 17 - scroll_offset
    led.text(x_pos, y_position, text, r, g, b)
  end

  led.show()
  time.delay(30)
end

function unload()
  print("Text Display unloaded")
  led.clear()
  led.show()
end
```

---

## 内存管理最佳实践

### 避免频繁创建表

```lua
-- ❌ 错误：每帧创建新表
function loop()
  local temp_table = {}  -- 增加 GC 压力
  -- 使用 temp_table
end

-- ✅ 正确：复用表
local temp_table = {}
function loop()
  -- 清空并复用
  for k in pairs(temp_table) do
    temp_table[k] = nil
  end
  -- 使用 temp_table
end
```

### 预分配数组

```lua
-- ✅ 好的做法
local particles = {}
for i = 1, 100 do
  particles[i] = {x = 0, y = 0, vx = 0, vy = 0}
end

-- ❌ 避免在循环中动态增长
```

---

## 代码组织最佳实践

### 使用模块化函数

```lua
local function init_particles()
  -- 初始化逻辑
end

local function update_particles()
  -- 更新逻辑
end

local function render_particles()
  -- 渲染逻辑
end

function setup()
  init_particles()
end

function loop()
  update_particles()
  render_particles()
  led.show()
  time.delay(30)
end
```

### 使用常量

```lua
-- 在文件顶部定义常量
local MAX_PARTICLES = 50
local UPDATE_INTERVAL = 100

-- 使用常量
for x = 0, WIDTH - 1 do
  for y = 0, HEIGHT - 1 do
    -- ...
  end
end
```

---

## 错误处理

### 检查配置值

```lua
local speed = CONFIG.speed or 100
if speed < 10 then speed = 10 end
if speed > 1000 then speed = 1000 end
```

### 验证硬件数据

```lua
local gx, gy, gz, valid = gravity.get()
if not valid then
  -- 使用默认值或跳过
  return
end
```

---

## 调试技巧

### 使用 print 输出

```lua
function setup()
  print("Module loaded")
  print("Config value:", CONFIG.speed or "not set")
end

function loop()
  local gx, gy = gravity.get()
  if time.millis() % 1000 == 0 then
    print("Gravity:", gx, gy)
  end
end
```

输出会显示在设备端串口监视器中。

---

## 技术限制

### 硬件限制
- LED 矩阵：17×8 像素
- 内存：有限，避免创建大量对象
- CPU：ESP32，避免复杂计算

### 软件限制
- Lua 版本：5.4.7
- 不支持文件 I/O
- 不支持网络操作
- 不支持多线程

### API 限制
- `led.text()` 仅支持 ASCII 0x20-0x7A
- `gravity.get()` 数据可能不可用（检查 `valid`）
- `fft.count()` 返回 512 个频段

---

## 故障排查

### 模块无法加载
1. 检查元数据格式是否正确
2. 确认文件名和 @id 使用连字符
3. 检查 Lua 语法错误（使用 `print` 调试）

### 配置不生效
1. 确认配置文件已上传
2. 检查 `CONFIG` 表是否正确读取
3. 验证配置键名与定义一致
4. 确认使用 `"desc"` 而不是 `"description"`

### LED 不显示
1. 确认调用了 `led.show()`
2. 检查坐标是否在范围内（x: 0-16, y: 0-7）
3. 验证颜色值是否正确（0-255）

### 性能问题
1. 减少 `loop()` 中的计算量
2. 增加 `time.delay()` 延迟
3. 使用局部变量和缓存
4. 避免频繁创建对象

---

**版本**: 2.0.0  
**更新时间**: 2026-05-29  
**适用设备**: Bottle (ESP32 + 17×8 LED 矩阵)

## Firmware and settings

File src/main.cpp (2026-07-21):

#include "common.h"
#include "rgb.h"
#include "touch.h"
#include "touch_icons.h"
#include "esp_sleep.h"
#include "sim_manager.h"
#include "sleep_manager.h"
#include "ble_config.h"
#include "app_control.h"
#include "module_registry.h"
#include "lua_hardware_api.h"
#include "auto_ota.h"
#include "time_calibration.h"
#include <Preferences.h>
#include "storage_flash.h"
#include "battery.h"
#include "gravity.h"
#include "audio_fft.h"
#include "usb_msc.h"
#include "cmd_handler.h"
#include <USB.h>
#include "tusb.h"
#if !ARDUINO_USB_CDC_ON_BOOT
USBCDC USBSerial;  // 定义全局对象（在 common.h 中声明为 extern）
#endif

// Button status enumeration for better code readability
enum ButtonStatus {
  BTN_NONE = 0,      // No action
  BTN_CLICK = 1,     // Short click (subpage switch)
  BTN_MODULE = 2,    // Long press - switch module
  BTN_SLEEP = 3,     // Very long press - enter sleep
  BTN_BLE = 4        // Long press - toggle BLE config
};

ButtonStatus btn_status = BTN_NONE;
uint32_t tm_chk_bat=0;
uint32_t tm_touch_begin;
uint8_t touch_hold_hint = 0;
uint8_t touch_hold_cycle = 0; //0=module, 1=ble, 2=sleep
uint32_t touch_hold_cycle_time = 0;

void main_load_config(){
  Preferences prefs;
  prefs.begin("bottle", true);
  page_index = prefs.getInt("page_index");
  user_brightness_max = prefs.getInt("brightness", user_brightness_max);
  s_idle_timeout_ms = prefs.getInt("sleep_sec",IDLE_TIMEOUT_DEFAULT)*1000;
  is_i2s_mic = prefs.getInt("i2s_mic",0);
  is_led = prefs.getInt("led",0);
  is_chk_bat = prefs.getInt("chk_bat",1);
  if (is_led)
      brightness_max=(int)(user_brightness_max/2+2);
  else
      brightness_max = user_brightness_max;
  prefs.end();
}

void main_save_config(){
  Preferences prefs;
  prefs.begin("bottle", false);
  prefs.putInt("page_index",page_index);
  prefs.putInt("brightness",user_brightness_max);
  prefs.end();

  const module_descriptor_t* module = module_registry_get((uint8_t)page_index);
  if (module && module->unload) {
    module->unload();
  }
}

int32_t app_get_page_count(void) {
  return module_registry_count();
}

int32_t app_get_page_index(void) {
  return page_index;
}

int32_t app_get_subpage_index(void) {
  return subpage_index;
}

void app_set_subpage(int32_t subpage) {
  subpage_index = subpage;
}

bool app_set_module_enabled(int32_t page, bool enabled) {
  if (page < 0 || page >= module_registry_count()) {
    return false;
  }

  bool was_enabled = module_registry_is_enabled((uint8_t)page);
  module_registry_set_enabled((uint8_t)page, enabled);
  bool now_enabled = module_registry_is_enabled((uint8_t)page);
  if (was_enabled == now_enabled) {
    return now_enabled == enabled;
  }

  if (!now_enabled && page == page_index) {
    const module_descriptor_t* current = module_registry_get((uint8_t)page_index);
    if (current && current->unload) {
      current->unload();
    }
    page_index = module_registry_normalize_index(page_index);
    subpage_index = 0;
    const module_descriptor_t* next = module_registry_get((uint8_t)page_index);
    if (next && next->setup) {
      next->setup();
    }
    if (is_led)
        brightness_max=(int)(user_brightness_max/2+2);
    else
        brightness_max = user_brightness_max;
    rgb_set_brightness(brightness_max);
  }

  return true;
}

void app_set_page(int32_t page, int32_t subpage) {
  if (page < 0 || page >= module_registry_count()) {
    return;
  }
  if (!module_registry_is_enabled((uint8_t)page)) {
    return;
  }

  if (page == page_index) {
    app_set_subpage(subpage);
    return;
  }

  const module_descriptor_t* current = module_registry_get((uint8_t)page_index);
  if (current && current->unload) {
    current->unload();
  }
  page_index = page;
  subpage_index = subpage;
  const module_descriptor_t* next = module_registry_get((uint8_t)page_index);
  if (next && next->setup) {
    next->setup();
  }
  if (is_led)
      brightness_max=(int)(user_brightness_max/2+2);
  else
      brightness_max = user_brightness_max;
  rgb_set_brightness(brightness_max);

  Preferences prefs;
  prefs.begin("bottle", false);
  prefs.putInt("page_index", page_index);
  prefs.end();
}

static bool touch_on_active_cb(touch_sensor_handle_t sens_handle, const touch_active_event_data_t *event, void *user_ctx)
{
    tm_touch_begin=millis();
    touch_hold_hint=0;
    return false;
}

static bool touch_on_inactive_cb(touch_sensor_handle_t sens_handle, const touch_inactive_event_data_t *event, void *user_ctx)
{
    uint32_t now=millis();
    uint32_t hold_duration = now - tm_touch_begin;

    // 如果当前模块声明了 button 权限，清除按住状态
    if (lua_hardware_is_button_used()) {
      lua_hardware_set_button_holding(false);
    }

    // 只有实际使用了 is_holding() 的模块才延长系统长按触发时间
    // 但在蓝牙模式下不延迟，保持快速退出蓝牙的能力
    uint32_t long_press_threshold = (lua_hardware_is_holding_used() && !ble_config_is_enabled()) ? 9000 : 800;

    if (hold_duration > long_press_threshold){
      // User held for more than 800ms, use the cycle indicator to determine action
      bool in_ble_mode = ble_config_is_enabled();

      if (in_ble_mode) {
        // In BLE mode: cycle 0 = BLE toggle, cycle 1 = Sleep
        if (touch_hold_cycle == 0) {
          btn_status = BTN_BLE;
        } else if (touch_hold_cycle == 1) {
          btn_status = BTN_SLEEP;
        }
      } else {
        // Normal mode: cycle 0 = Module, cycle 1 = BLE, cycle 2 = Sleep
        if (touch_hold_cycle == 0) {
          btn_status = BTN_MODULE;
        } else if (touch_hold_cycle == 1) {
          btn_status = BTN_BLE;
        } else if (touch_hold_cycle == 2) {
          btn_status = BTN_SLEEP;
        }
      }
    }
    else if (now-tm_touch_begin>100){
      btn_status = BTN_CLICK;
    }

    tm_touch_begin=0;
    touch_hold_hint=0;
    touch_hold_cycle=0;
    return false;
}

void check_btn(){
  uint32_t now = millis();
  if (tm_touch_begin>0) {
    uint32_t held = now - tm_touch_begin;

    // 如果当前模块声明了 button 权限，在按住超过300ms后设置holding状态
    if (lua_hardware_is_button_used() && held > 300) {
      lua_hardware_set_button_holding(true);
    }

    // 只有实际使用了 is_holding() 的模块才延长系统长按触发时间，避免与 Lua 脚本的长按逻辑冲突
    // 但在蓝牙模式下不延迟，保持快速退出蓝牙的能力
    uint32_t long_press_threshold = (lua_hardware_is_holding_used() && !ble_config_is_enabled()) ? 9000 : 800;

    if (held > long_press_threshold && touch_hold_hint < 1) {
      // Start cycling through icons
      touch_hold_hint = 1;
      bool in_ble_mode = ble_config_is_enabled();
      // In BLE mode, start from BLE icon (cycle 0), otherwise start from module icon (cycle 0)
      touch_hold_cycle = 0;
      touch_hold_cycle_time = now;

      if (in_ble_mode) {
        show_ble_hold_hint(true);  // Show slash in BLE mode (turn off)
      } else {
        show_module_hold_hint();
      }
    } else if (held > 15000) {
      btn_status = BTN_SLEEP;
    } else if (held > long_press_threshold) {
      // Cycling mode: update icon every 1000ms
      if (now - touch_hold_cycle_time > 1000) {
        bool in_ble_mode = ble_config_is_enabled();

        if (in_ble_mode) {
          // In BLE mode: cycle between BLE (0) and Sleep (1)
          touch_hold_cycle = (touch_hold_cycle + 1) % 2;
          touch_hold_cycle_time = now;

          if (touch_hold_cycle == 0) {
            show_ble_hold_hint(true);  // Show slash in BLE mode (turn off)
          } else if (touch_hold_cycle == 1) {
            show_sleep_hold_hint();
          }
        } else {
          // Normal mode: cycle between Module (0), BLE (1), Sleep (2)
          touch_hold_cycle = (touch_hold_cycle + 1) % 3;
          touch_hold_cycle_time = now;

          if (touch_hold_cycle == 0) {
            show_module_hold_hint();
          } else if (touch_hold_cycle == 1) {
            show_ble_hold_hint(false);  // No slash in normal mode (turn on)
          } else if (touch_hold_cycle == 2) {
            show_sleep_hold_hint();
          }
        }
      }
    }
  }
  if (btn_status == BTN_CLICK){
    btn_status = BTN_NONE;
    if (ble_config_is_enabled()) {
      return;
    }
    // 检查当前模块是否声明了 button 权限
    if (lua_hardware_is_button_used()) {
      lua_hardware_send_button_event(1);  // 1 = click
      return;
    }
    subpage_index++;
  }
  else if (btn_status == BTN_MODULE){
    if (ble_config_is_enabled()) {
      btn_status = BTN_NONE;
      return;
    }
    btn_status = BTN_NONE;
    const module_descriptor_t* current = module_registry_get((uint8_t)page_index);
    if (current && current->unload) {
      current->unload();
    }

    page_index = module_registry_next_enabled(page_index);
    if (page_index < 0) {
      page_index = module_registry_normalize_index(0);
    }
    subpage_index=0;

    const module_descriptor_t* next = module_registry_get((uint8_t)page_index);
    if (next && next->setup) {
      next->setup();
    }
    if (is_led)
        brightness_max=(int)(user_brightness_max/2+2);
    else
        brightness_max = user_brightness_max;
    FastLED.setBrightness(brightness_max);

  }
  else if (btn_status == BTN_BLE){
    btn_status = BTN_NONE;
    ble_config_toggle();
    if (!ble_config_is_enabled()){ //退出蓝牙后重新启动模块
      // 重置休眠计时器，避免立即休眠
      sleep_manager_reset_idle_timer();

      const module_descriptor_t* current = module_registry_get((uint8_t)page_index);
      int ret;
      if (current && current->unload) {
        ret = current->unload();
      }
      if (current && current->setup) {
        ret = current->setup();
      }
    }
  }
  else if (btn_status == BTN_SLEEP){
    // Sleep action - save config and enter deep sleep
    main_save_config();
    enter_deep_sleep();
  }
}

void setup() {
  // 1. 先初始化 USB CDC
  #if !ARDUINO_USB_CDC_ON_BOOT
  USBSerial.begin();
  #endif

  // 2. 启动 USB 栈（仅 CDC，不启动 MSC）
  USB.begin();
  Serial.setDebugOutput(true);
  log_e("=== Bottle System Starting ===");
  log_e("Firmware Version: %s", FIRMWARE_VERSION);
  log_e("Build Date: %s %s", __DATE__, __TIME__);

  // 5. 初始化存储（正常挂载文件系统供设备使用）
  storage_init();

  pinMode(LED_SWITCH_PIN, OUTPUT);
  digitalWrite(LED_SWITCH_PIN, LOW);
  rgb_init();

  // 6. 检查并执行自动 OTA 更新（如果有 firmware.bin）
  if (auto_ota_check_and_update()) {
    // OTA 更新执行中或失败，函数内部会处理重启或清理
    // 如果到这里说明更新失败，继续正常启动
    log_e("[Setup] OTA update failed or completed, continuing normal boot");
  }

  // 7. 恢复时区设置
  restore_timezone();

  // 8. 初始化时间校准模块
  TimeCalibration::init();

  if (usb_msc_init()) {
    log_e("[Setup] USB MSC enabled - device is now a USB drive");
  } else {
    log_e("[Setup] Failed to enable USB MSC");
  }

  if (is_chk_bat)
    check_battery_init();

  main_load_config();

  gravity_init();
  if (s_idle_timeout_ms>0)
    gravity_sensor_start();

  touch_sleep_init(touch_on_active_cb,touch_on_inactive_cb);

  module_registry_init();

  page_index = module_registry_normalize_index(page_index);

  const module_descriptor_t* module = module_registry_get((uint8_t)page_index);
  if (module && module->setup) {
    module->setup();
  }

  // Restore user brightness after module setup
  if (is_led)
      brightness_max=(int)(user_brightness_max/2+2);
  else
      brightness_max = user_brightness_max;
  FastLED.setBrightness(brightness_max);

  sleep_manager_init();

  sleep_manager_start();
}

void loop() {

  check_btn();

  if (is_chk_bat && millis() - tm_chk_bat > 30000) { // 每30秒检查一次电池状态
    tm_chk_bat = millis();
    check_bat();
    if (is_low_bat) {
      draw_low_battery_hint();
      enter_deep_sleep();
    }
  }

  if (tm_touch_begin > 0 && touch_hold_hint > 0) {
    delay(10);
    return;
  }

  check_cmd();

  // 检测 USB 连接状态
  static bool last_usb_connected = false;
  bool usb_connected = tud_connected() && tud_mounted() && !tud_suspended();

  // 额外检测：如果 MSC 已启用但 USB 未连接，说明 USB 被拔掉了
  if (usb_msc_is_enabled() && !usb_connected) {
    static uint32_t last_disconnect_check = 0;
    if (millis() - last_disconnect_check > 1000) {
      last_disconnect_check = millis();
      log_e("[USB] MSC enabled but USB not connected - forcing deinit");
      usb_msc_deinit();
      last_usb_connected = false;
    }
  }

  if (usb_connected != last_usb_connected) {
    if (usb_connected) {
      log_e("[USB] Connected and mounted");
      if (!usb_msc_is_enabled()) {
        log_e("[USB] Auto-enabling MSC");

        usb_msc_init();
      }
    } else {
      log_e("[USB] Disconnected");
      if (usb_msc_is_enabled()) {
        log_e("[USB] Auto-disabling MSC, remounting storage");
        usb_msc_deinit();
      }
    }
    last_usb_connected = usb_connected;
  }

  ble_config_update();

  if (ble_config_is_enabled()) {
    ble_config_render_mode();
    delay(30);
    return;
  }

  sleep_manager_update();

  // Skip module rendering when showing touch hold hint
  if (tm_touch_begin > 0 && touch_hold_hint > 0) {
    delay(10);
    return;
  }

  const module_descriptor_t* module = module_registry_get((uint8_t)page_index);
  if (module && module->loop) {
    module->loop();
  }

  delay(10);

}

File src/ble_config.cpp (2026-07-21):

#include "ble_config.h"
#include "ble_security.h"
#include "app_control.h"
#include "common.h"
#include "module_registry.h"
#include "rgb.h"
#include "sleep_manager.h"
#include "touch_icons.h"
#include "time_calibration.h"
#include <Arduino.h>
#include <NimBLEDevice.h>
#include <sys/time.h>
#include <time.h>

// RTC 内存变量，深度休眠期间保持
RTC_DATA_ATTR int rtc_timezone_offset = 0;
RTC_DATA_ATTR bool rtc_timezone_valid = false;

// 设置时区的辅助函数
void set_timezone(int offset) {
    char tz_str[16];
    snprintf(tz_str, sizeof(tz_str), "UTC%+d", -offset);
    setenv("TZ", tz_str, 1);
    tzset();

    // 保存到 RTC 内存
    rtc_timezone_offset = offset;
    rtc_timezone_valid = true;
}

// 恢复时区设置（在启动时调用）
void restore_timezone() {
    if (rtc_timezone_valid) {
        char tz_str[16];
        snprintf(tz_str, sizeof(tz_str), "UTC%+d", -rtc_timezone_offset);
        setenv("TZ", tz_str, 1);
        tzset();
        Serial.printf("Restored timezone: UTC%+d\n", rtc_timezone_offset);
    }
}

#include <Preferences.h>
#include <base64.h>
#include <sys/stat.h>

// 外部变量声明
extern uint32_t s_idle_timeout_ms;

#define BLE_SERVICE_UUID "8c0b8a10-7e3d-4df7-9a2a-1d8d46f8b100"
#define BLE_CONFIG_CHAR_UUID "8c0b8a11-7e3d-4df7-9a2a-1d8d46f8b100"
#define BLE_STATUS_CHAR_UUID "8c0b8a12-7e3d-4df7-9a2a-1d8d46f8b100"
#define BLE_PASSWORD_CHAR_UUID "8c0b8a13-7e3d-4df7-9a2a-1d8d46f8b100"
#define BLE_AUTH_CHAR_UUID "8c0b8a14-7e3d-4df7-9a2a-1d8d46f8b100"

static NimBLECharacteristic* s_status_char = nullptr;
static NimBLECharacteristic* s_password_char = nullptr;
static NimBLECharacteristic* s_auth_char = nullptr;
static NimBLEServer* s_ble_server = nullptr;
static NimBLEAdvertising* s_ble_advertising = nullptr;
static String s_pending_cmd;
static bool s_has_pending_cmd = false;
static bool s_client_connected = false;
bool s_ble_enabled = false;
static bool s_ble_initialized = false;

// 安全管理器
static DeviceSecurity deviceSecurity;

// File upload state
static bool s_upload_in_progress = false;
static String s_upload_module_id;
static String s_upload_filename;
static size_t s_upload_size = 0;
static size_t s_upload_received = 0;
static FILE* s_upload_file = nullptr;

// Config definition upload state
static bool s_config_def_in_progress = false;

// Color display state
static bool s_show_color = false;
static uint8_t s_color_r = 0;
static uint8_t s_color_g = 0;
static uint8_t s_color_b = 0;
static String s_config_def_module_id;
static String s_config_def_buffer;
static size_t s_config_def_size = 0;
static size_t s_config_def_received = 0;

// Simple base64 decode table
static const char base64_chars[] = "ABCDEFGHIJKLMNOPQRSTUVWXYZabcdefghijklmnopqrstuvwxyz0123456789+/";

static int base64_decode_char(char c) {
    if (c >= 'A' && c <= 'Z') return c - 'A';
    if (c >= 'a' && c <= 'z') return c - 'a' + 26;
    if (c >= '0' && c <= '9') return c - '0' + 52;
    if (c == '+') return 62;
    if (c == '/') return 63;
    return -1;
}

static size_t base64_decode(const char* input, size_t input_len, uint8_t* output) {
    size_t output_len = 0;
    uint32_t buffer = 0;
    int bits = 0;

    for (size_t i = 0; i < input_len; i++) {
        if (input[i] == '=') break;

        int value = base64_decode_char(input[i]);
        if (value < 0) continue;

        buffer = (buffer << 6) | value;
        bits += 6;

        if (bits >= 8) {
            bits -= 8;
            output[output_len++] = (buffer >> bits) & 0xFF;
        }
    }

    return output_len;
}

static bool extract_int(const String& json, const char* key, int* out) {
    String marker = String("\"") + key + "\"";
    int pos = json.indexOf(marker);
    if (pos < 0) return false;

    pos = json.indexOf(':', pos + marker.length());
    if (pos < 0) return false;
    pos++;

    while (pos < (int)json.length() && isspace((unsigned char)json[pos])) pos++;

    int end = pos;
    if (end < (int)json.length() && (json[end] == '-' || json[end] == '+')) end++;
    while (end < (int)json.length() && isdigit((unsigned char)json[end])) end++;
    if (end == pos) return false;

    *out = json.substring(pos, end).toInt();
    return true;
}

static bool extract_string(const String& json, const char* key, String* out) {
    String marker = String("\"") + key + "\"";
    int pos = json.indexOf(marker);
    if (pos < 0) return false;

    pos = json.indexOf(':', pos + marker.length());
    if (pos < 0) return false;
    pos++;

    while (pos < (int)json.length() && isspace((unsigned char)json[pos])) pos++;
    if (pos >= (int)json.length() || json[pos] != '"') return false;
    pos++;

    int end = json.indexOf('"', pos);
    if (end < 0) return false;

    *out = json.substring(pos, end);
    return true;
}
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

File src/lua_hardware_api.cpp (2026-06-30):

#include "lua_hardware_api.h"

#include <Arduino.h>
#include <FastLED.h>
#include <Preferences.h>
#include "app_control.h"
#include "audio_fft.h"
#include "audio_record.h"
#include "common.h"
#include "gravity.h"
#include "ble_mouse.h"
#include "sleep_manager.h"
#include "time_calibration.h"

extern "C" {
#include "lua.h"
#include "lualib.h"
#include "lauxlib.h"
}

namespace {

// 全局重力数据快照（由调用者更新）
struct GravitySnapshot {
  float x, y, z;
  bool valid;
};

GravitySnapshot g_gravity_snapshot = {0, 0, 0, false};

// 资源使用标志
bool g_use_gravity = false;
bool g_use_audio = false;
bool g_use_button = false;

// 按键事件回调
struct ButtonEvent {
  enum Type { NONE = 0, CLICK = 1, LONG_PRESS = 2 };
  Type type;
  uint32_t timestamp;
};

ButtonEvent g_button_event = {ButtonEvent::NONE, 0};
bool g_button_is_holding = false;  // 按键是否正在被按住
bool g_button_is_holding_used = false;  // 当前模块是否使用了 is_holding() 函数

}  // namespace

// 更新重力传感器快照（由外部调用）
void lua_hardware_update_gravity() {
  gravity_xy_t g = gravity_get();
  g_gravity_snapshot.valid = g.valid;
  g_gravity_snapshot.x = g.gx;
  g_gravity_snapshot.y = g.gy;
  g_gravity_snapshot.z = g.gz;
}

// 启动已声明的硬件资源
void lua_hardware_start_resources() {
  if (g_use_gravity) {
    Serial.println("Lua: Starting gravity sensor...");
    int result = gravity_sensor_start();
    if (result == 0) {
      Serial.println("Lua: Gravity sensor started");
    } else {
      Serial.println("Lua: Failed to start gravity sensor");
    }
  }

  if (g_use_audio) {
    Serial.println("Lua: Starting audio FFT...");
    int init_result = audio_fft_init();
    if (init_result == 0) {
      int start_result = audio_fft_start();
      if (start_result == 0) {
        Serial.println("Lua: Audio FFT started");
      } else {
        Serial.println("Lua: Failed to start audio FFT");
      }
    } else {
      Serial.println("Lua: Failed to init audio FFT");
    }
  }
}

// 停止所有硬件资源
void lua_hardware_stop_resources() {
  if (g_use_gravity) {
    Serial.println("Lua: Stopping gravity sensor...");
    if (s_idle_timeout_ms==0)
      gravity_sensor_sleep();
    g_use_gravity = false;
  }

  if (g_use_audio) {
    Serial.println("Lua: Stopping audio FFT...");
    audio_fft_stop();
    g_use_audio = false;
  }

  if (g_use_button) {
    Serial.println("Lua: Releasing button control...");
    g_use_button = false;
    g_button_event.type = ButtonEvent::NONE;
    g_button_is_holding = false;
    g_button_is_holding_used = false;  // 重置 is_holding 使用标志
  }
}

// ============================================================================
// LED API
// ============================================================================

// led.clear()
static int lua_led_clear(lua_State* L) {
  FastLED.clear();
  return 0;
}

// led.show()
static int lua_led_show(lua_State* L) {
  FastLED.show();
  return 0;
}

// led.set(x, y, r, g, b)
static int lua_led_set(lua_State* L) {
  int x = (int)luaL_checknumber(L, 1);
  int y = (int)luaL_checknumber(L, 2);
  int r = (int)luaL_checknumber(L, 3);
  int g = (int)luaL_checknumber(L, 4);
  int b = (int)luaL_checknumber(L, 5);

  if (x >= 0 && x < MATRIX_WIDTH && y >= 0 && y < MATRIX_HEIGHT) {
    leds(x, y) = CRGB(r, g, b);
  }
  return 0;
}

// led.hsv(h, s, v) -> returns r, g, b
static int lua_led_hsv(lua_State* L) {
  int h = (int)luaL_checknumber(L, 1);
  int s = (int)luaL_checknumber(L, 2);
  int v = (int)luaL_checknumber(L, 3);

  CRGB color = CHSV(h, s, v);
  lua_pushnumber(L, color.r);
  lua_pushnumber(L, color.g);
  lua_pushnumber(L, color.b);
  return 3;
}
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

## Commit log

2026-05-02 泛光效果
2026-05-02 火苗分层，重力感应
2026-05-02 沙漏重力感应
2026-05-02 蓝牙开启与配置
2026-05-05 VM引擎
    [partitions.csv]
2026-05-06 数组支持浮点数
2026-05-06 使用lua
2026-05-06 抽象硬件层
2026-05-06 优化休眠功耗
2026-05-06 唤醒灵敏度
2026-05-06 火焰重力感应调整
2026-05-06 频谱代码lua化
2026-05-06 lua开发指南
2026-05-06 触摸btn改为枚举类型
2026-05-06 关机图标优化
2026-05-07 应用市场下载管理
2026-05-08 lua延迟函数
2026-05-08 传输模块列表bug修复
2026-05-08 蓝牙图标及启停逻辑
2026-05-08 lua支持use声明硬件资源
2026-05-08 去除内置彩色波浪
2026-05-08 打砖块移动到市场
2026-05-08 分块发送，音律添加配置项
2026-05-08 清除打印
2026-05-08 退出蓝牙断开连接，重新加载模块，流体配置
2026-05-10 BLE绑定解绑+业务验证
2026-05-10 关机图标调整
2026-05-11 native/lua模块统一配置，内置字体
2026-05-11 退出蓝牙重置休眠计数器，下拉bug修复，文档刷新
2026-05-12 添加俄罗斯方块
2026-05-12 音律子模块切换通过按钮
2026-05-16 音律卸载统一申请释放资源
2026-05-16 lis3dh加速度计支持
2026-05-16 编译时间优化
2026-05-18 低电压告警，存储初始化，蓝牙模式清屏
2026-05-20 加速度计用正确的地址和参数
2026-05-20 条件编译支持I2S与PDM麦
2026-05-20 新增蓝牙鼠标能力
2026-05-20 加速度计校准
2026-05-20 加速度计启停逻辑优化，配置休眠时间时常开
2026-05-20 设备信息同步
2026-05-20 命令行切换i2s/pdm麦
2026-05-21 录音能力，U盘
2026-05-21 PCB硬件设计
    [Bottle-v2.2.PrjPcb, bottle.PcbDoc, led_array.schdoc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]
2026-05-21 音频增益
2026-05-21 说明文档
2026-05-21 文档优化
2026-05-22 BOM清单补全
    [BOM.xlsx, Bottle-v2.2.PrjPcb, bottle.PcbDoc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]
2026-05-22 调色板颜色预览
2026-05-22 优化颜色处理逻辑，显示色与设置值保持一致
2026-05-22 连接小程序做设备时间同步
2026-05-22 海洋添加水位涨潮配置项
2026-05-22 沙漏颜色流速配置
2026-05-22 沙漏流速
2026-05-22 清除文件
2026-05-22 火焰颜色
2026-05-22 u盘与串口复合使用
    [partitions.csv]
2026-05-23 U盘状态检测处理
2026-05-23 硬件组件说明
    [BOM.xlsx]
2026-05-23 修复弹出逻辑
2026-05-23 触摸按钮说明
2026-05-24 统一文件系统操作api，统一模块配置文件
    [candle.cfg, rhythm.cfg, sandglass.cfg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]
2026-05-24 蜡烛火焰添加自定义颜色开关
    [candle.cfg]
2026-05-24 兼容两款麦克风
2026-05-24 校准命令优化
2026-05-25 短配置字符串更新配置数量
2026-05-25 支持从spi nandflash新增lua模块
2026-05-25 触摸阈值
2026-05-25 switch默认配置处理，重力旋转文字支持，lua层时间函数
2026-05-26 去除加速度计校准代码，硬件问题换硬件
2026-05-26 添加解绑命令
2026-05-26 修改MTU适配IOS
2026-05-26 添加OTA功能
2026-05-27 更新文档
2026-05-27 烧录说明
2026-05-28 海洋流体模拟配置说明
    [water.cfg]
2026-05-29 触摸阈值调整
2026-05-29 如果lua使用了is_holding，将推迟系统切换模块时间9秒
2026-05-30 低电压阈值调整
2026-05-31 lua开发文档整理
2026-05-31 添加nvs命令，处理模块无id的问题
2026-05-31 lua函数更新
2026-06-01 将音律作为lua调整至spiffs中
2026-06-01 lua开发文档添加描述长度限制
2026-06-04 低电量测量开关
2026-06-13 长版兼容性调整，蓝牙图标居中，屏幕绘制方向定义
2026-06-13 实现pc上的lua模拟器
2026-06-14 通过每次同步时间计算漂移率获取高精度时间
2026-06-14 修改内置动画支持长版
2026-06-14 长版音律
    [rhythm-long.cfg]
2026-06-14 lua模拟器说明
2026-06-14 lua模拟器使用说明
2026-06-14 分长短版优化测量电池电压，长版有分压电路
2026-06-15 模拟器重力模拟优化
2026-06-15 lua不提交
2026-06-15 lua模拟器clamp函数补齐
2026-06-15 说明文档lua示例去除硬编码宽高
2026-06-15 文档完善
2026-06-20 长版电压检测阈值调整
2026-06-30 lua开发指南刷新
2026-06-30 配置项解析问题修复
2026-07-05 模拟器增加path.pow函数
2026-07-05 模拟器增加函数
2026-07-21 加入对12mA LED的支持
    [rhythm.cfg]
2026-07-24 长短版定义
2026-07-24 长短版编译说明
2026-07-24 更新board和说明
